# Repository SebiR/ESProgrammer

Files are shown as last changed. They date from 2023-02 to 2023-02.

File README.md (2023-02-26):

# ESProgrammer
A simple USB programming interface for ESP8266/ESP32

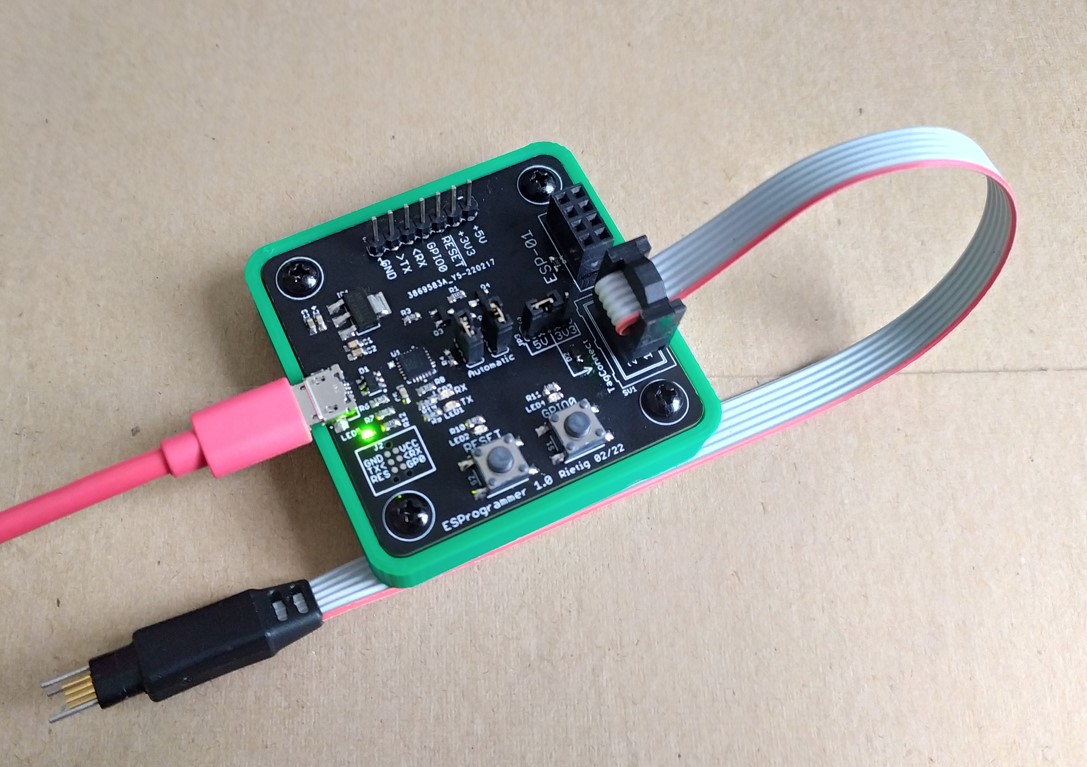
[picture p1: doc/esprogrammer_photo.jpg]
Programmer


## Features
* Automatic Reset/GPIO0
* TagConnect interface for custom devices
* Direct connector for ESP-01 modules

# Pinout and TagConnect
**RX of Programmer to RX of ESP and TX to TX**
(Which is a bit confusing to be honest)

The TagConnect connector follows my own standard which I've created for my devices using an ESP8266.

The device should utilize this pinout:
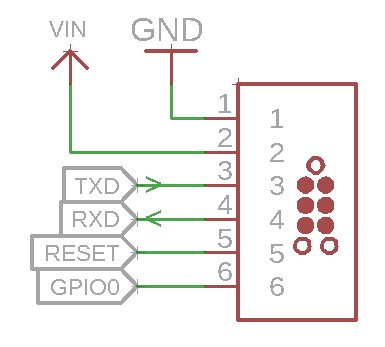
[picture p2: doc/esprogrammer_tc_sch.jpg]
Programmer


Whereas TXD goes to the TXD of the ESP8266 and RXD goes to the RXD of the ESP.

# Jumper
## Automatic
The two "Automatic" jumpers allow for an automatic trigger of the Reset and GPIO0 line during programming like on NodeMCU boards and Tasmotizer.
Manual resetting and triggering GPIO0 will always be possible with the push buttons.

## 3V3/5V
The other jumper near the TagConnect allows for a selection of the power supply voltage of the TagConnect. When my device has an LDO and 5V power supply, VCC will be set to 5V and the VCC pin on the device goes to the 5V input of the board.

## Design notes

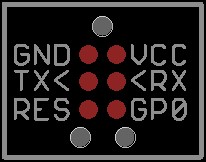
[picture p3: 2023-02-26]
doc/esprogrammer_tc.jpg

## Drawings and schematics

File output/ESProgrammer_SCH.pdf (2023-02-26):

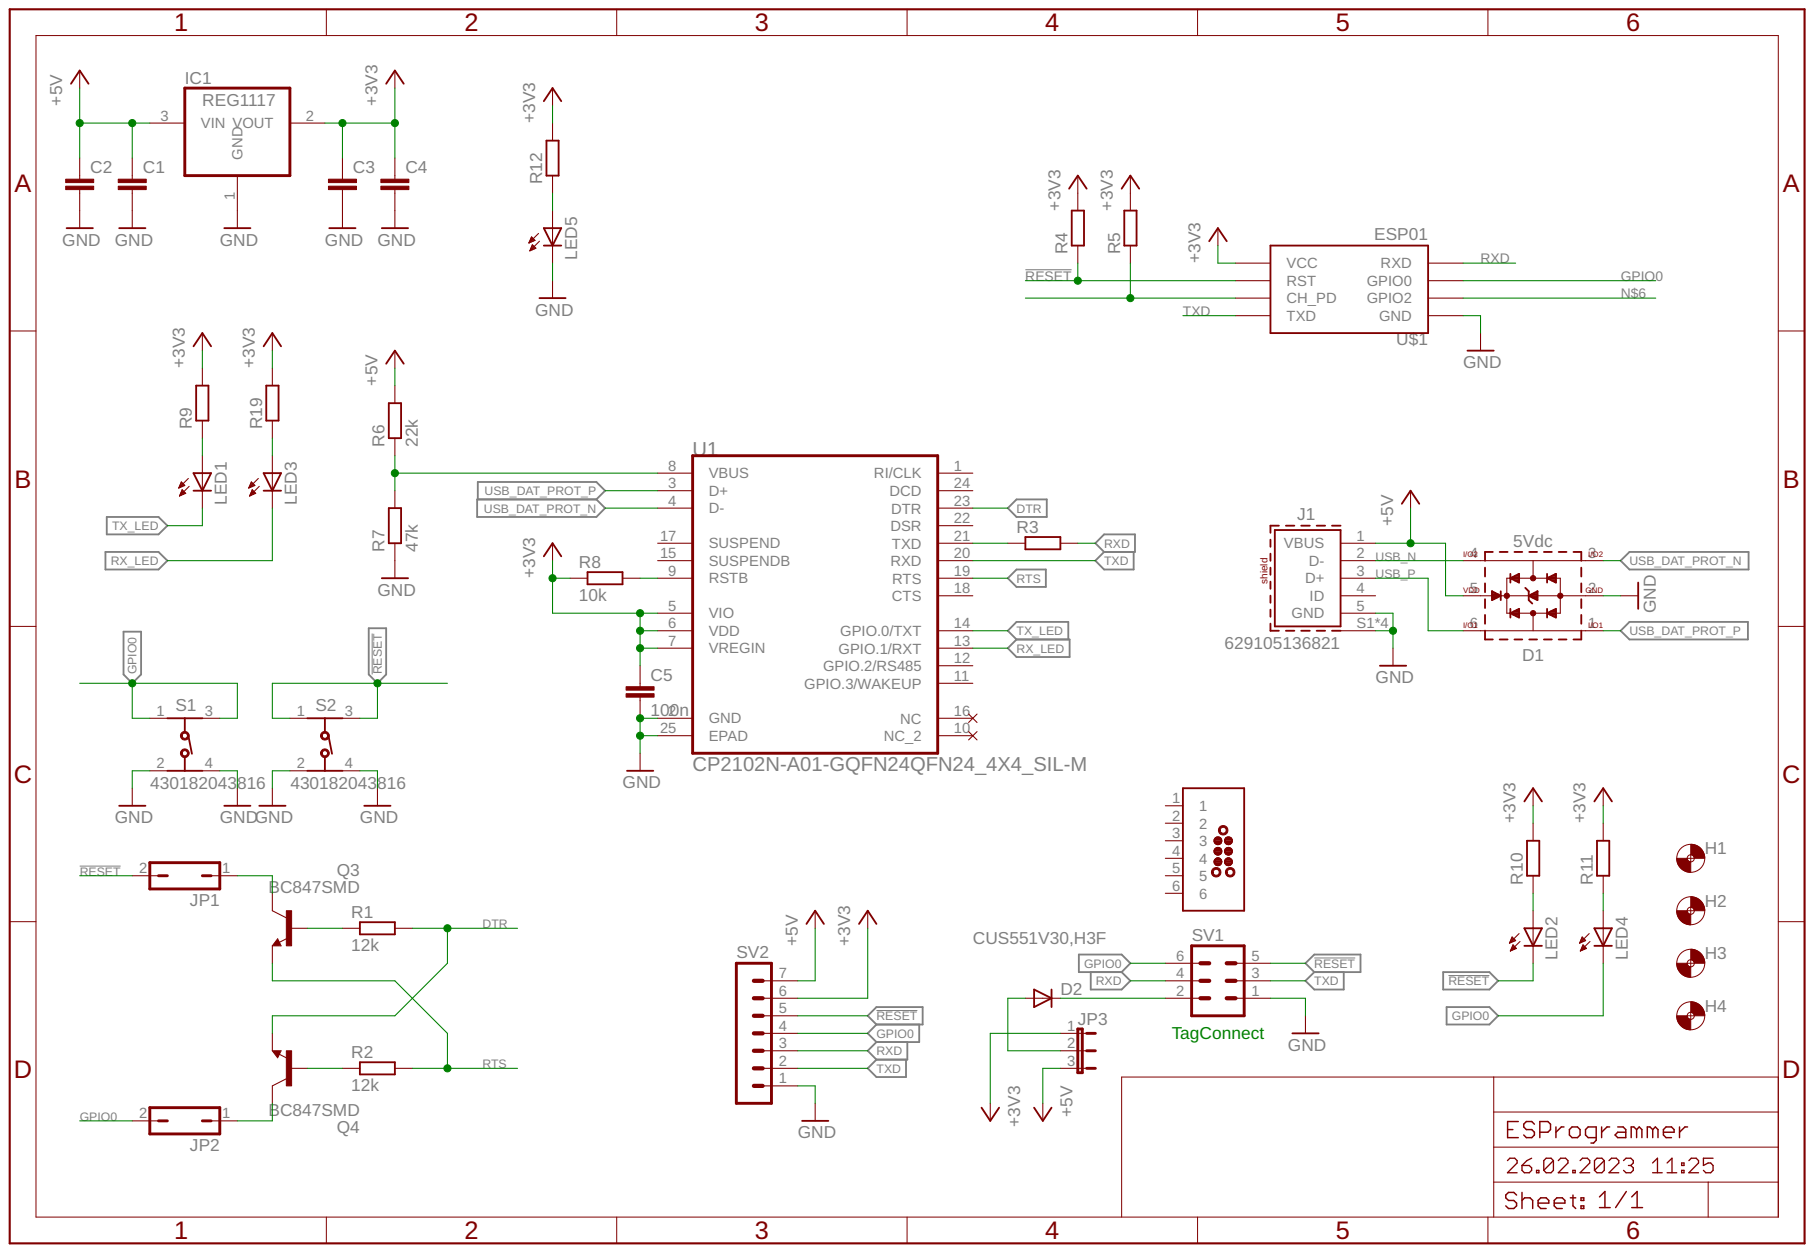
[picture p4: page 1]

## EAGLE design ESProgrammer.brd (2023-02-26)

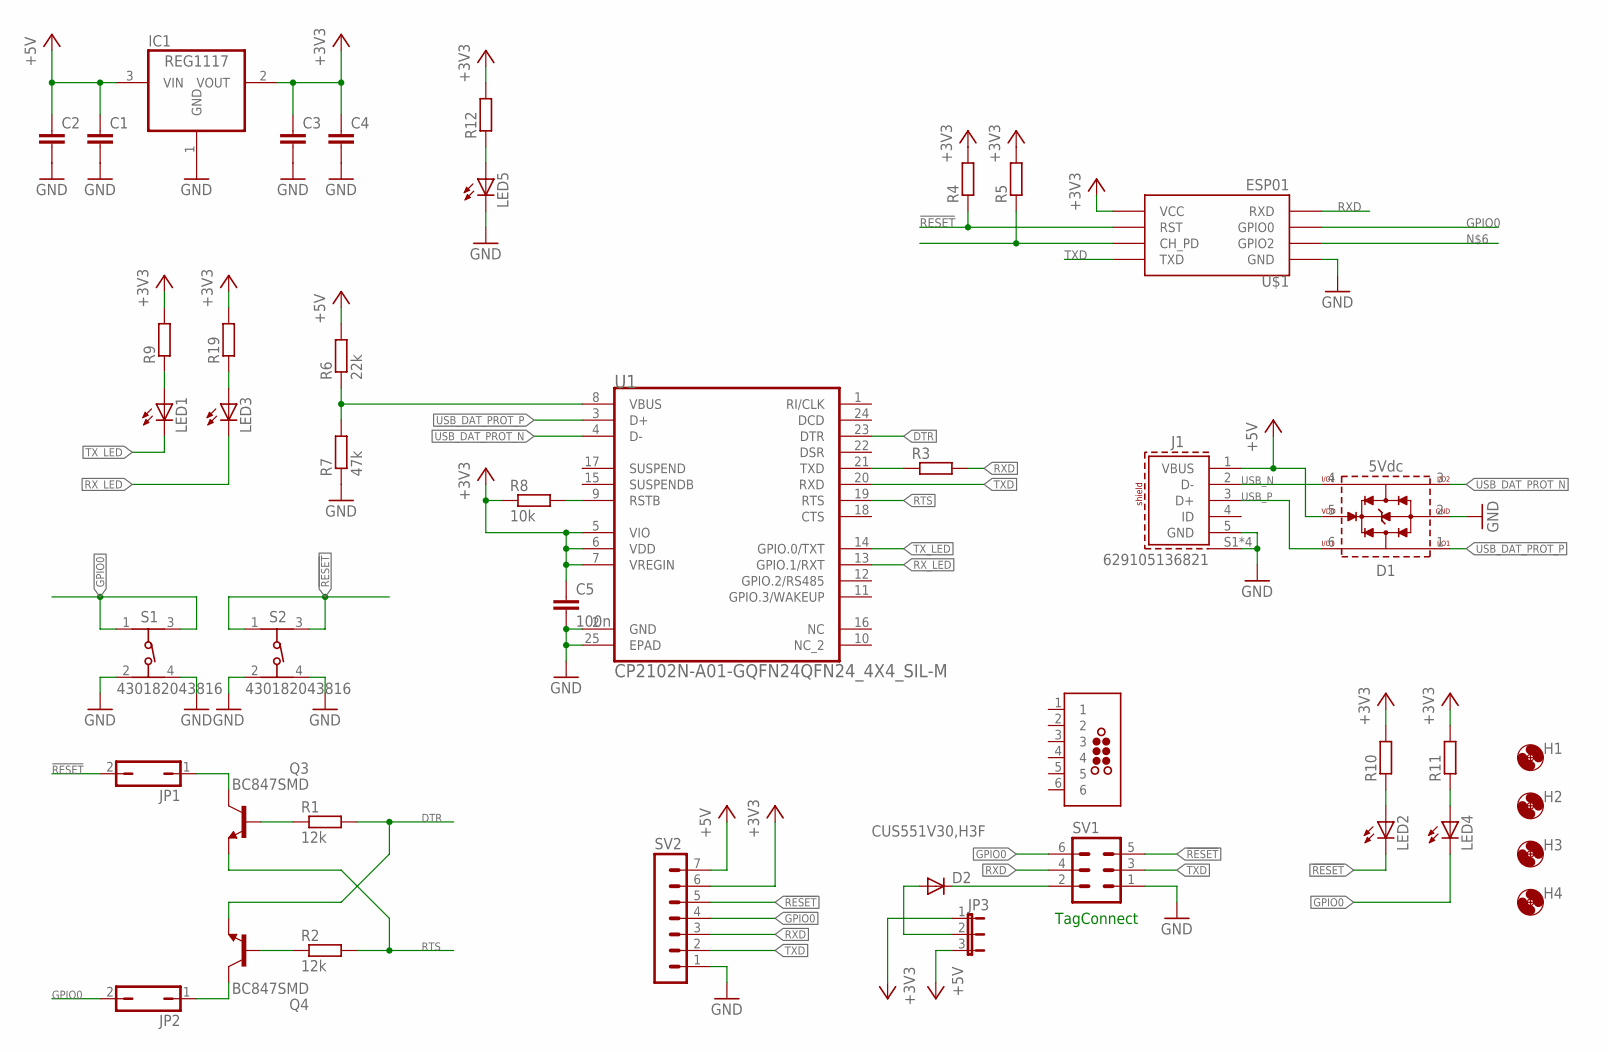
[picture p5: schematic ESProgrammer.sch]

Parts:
C1, C2, C3, C4: C-EUC0603; C0603
C5: 100n; C0603
D1: 5Vdc; WE-TVS_SOT23-6L
D2: CUS551V30,H3F; SOD323-R
H1, H2, H3, H4: MOUNT-HOLE3.2; 3,2
IC1: REG1117; SOT223
J1: 629105136821
J2: TC2030-MCP-NL
JP1, JP2: JP1Q; JP1
JP3: JP2E; JP2
LED1, LED2, LED3, LED4, LED5: LEDCHIP-LED0603; CHIP-LED0603
Q3, Q4: BC847SMD; SOT23
R1, R2: 12k; R0603
R3, R4, R5, R9, R10, R11, R12, R19: R-EU_R0603; R0603
R6: 22k; R0603
R7: 47k; R0603
R8: 10k; R0603
S1, S2: 430182043816
SV1: ML6
SV2: MA07-1
U1: CP2102N-A01-GQFN24QFN24_4X4_SIL-M; QFN24_4X4_SIL-M
U$1: ESP01

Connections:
2: J2.2
3: J2.3
!RESET: JP1.2, LED2.C, R4.1, S2.1, S2.3, SV1.5, SV2.5, U$1.RST
+3V3: C3.1, C4.1, C5.1, IC1.2 (VOUT), JP3.1, R4.2, R5.2, R8.1, R9.2, R10.2, R11.2, R12.2, R19.2, SV2.6, U1.5 (VIO), U1.6 (VDD), U1.7 (VREGIN), U$1.VCC
+5V: C1.1, C2.1, D1.5 (VDD), IC1.3 (VIN), J1.1 (VBUS), JP3.3, R6.2, SV2.7
DTR: Q4.2 (E), R1.2, U1.23 (DTR)
GND: C1.2, C2.2, C3.2, C4.2, C5.2, D1.2 (GND), IC1.1 (GND), J1.5 (GND), J1.S1 (SHIELD), J1.S2 (SHIELD), J1.S3 (SHIELD), J1.S4 (SHIELD), LED5.C, R7.1, S1.2, S1.4, S2.2, S2.4, SV1.1, SV2.1, U1.2 (GND), U1.25 (EPAD), U$1.GND
GPIO0: JP2.2, LED4.C, S1.1, S1.3, SV1.6, SV2.4, U$1.GPIO0
unnamed: Q3.1 (B), R1.1
unnamed: Q4.1 (B), R2.1
unnamed: JP1.1, Q3.3 (C)
unnamed: JP2.1, Q4.3 (C)
unnamed: R3.1, U1.21 (TXD)
unnamed: R5.1, U$1.CH_PD
unnamed: LED1.A, R9.1
unnamed: LED2.A, R10.1
unnamed: R6.1, R7.2, U1.8 (VBUS)
unnamed: R8.2, U1.9 (RSTB)
unnamed: LED4.A, R11.1
unnamed: LED5.A, R12.1
unnamed: D2.A, JP3.2
unnamed: D2.C, SV1.2
unnamed: LED3.A, R19.1
RTS: Q3.2 (E), R2.2, U1.19 (RTS)
RXD: R3.2, SV1.4, SV2.3, U$1.RX (RXD)
RX_LED: LED3.C, U1.13 (GPIO.1/RXT)
TXD: SV1.3, SV2.2, U1.20 (RXD), U$1.TX (TXD)
TX_LED: LED1.C, U1.14 (GPIO.0/TXT)
USB_DAT_PROT_N: D1.3 (I/O2), U1.4 (D-)
USB_DAT_PROT_P: D1.1 (I/O1), U1.3 (D+)
USB_N: D1.4 (I/O4), J1.2 (D-)
USB_P: D1.6 (I/O3), J1.3 (D+)

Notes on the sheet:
TagConnect

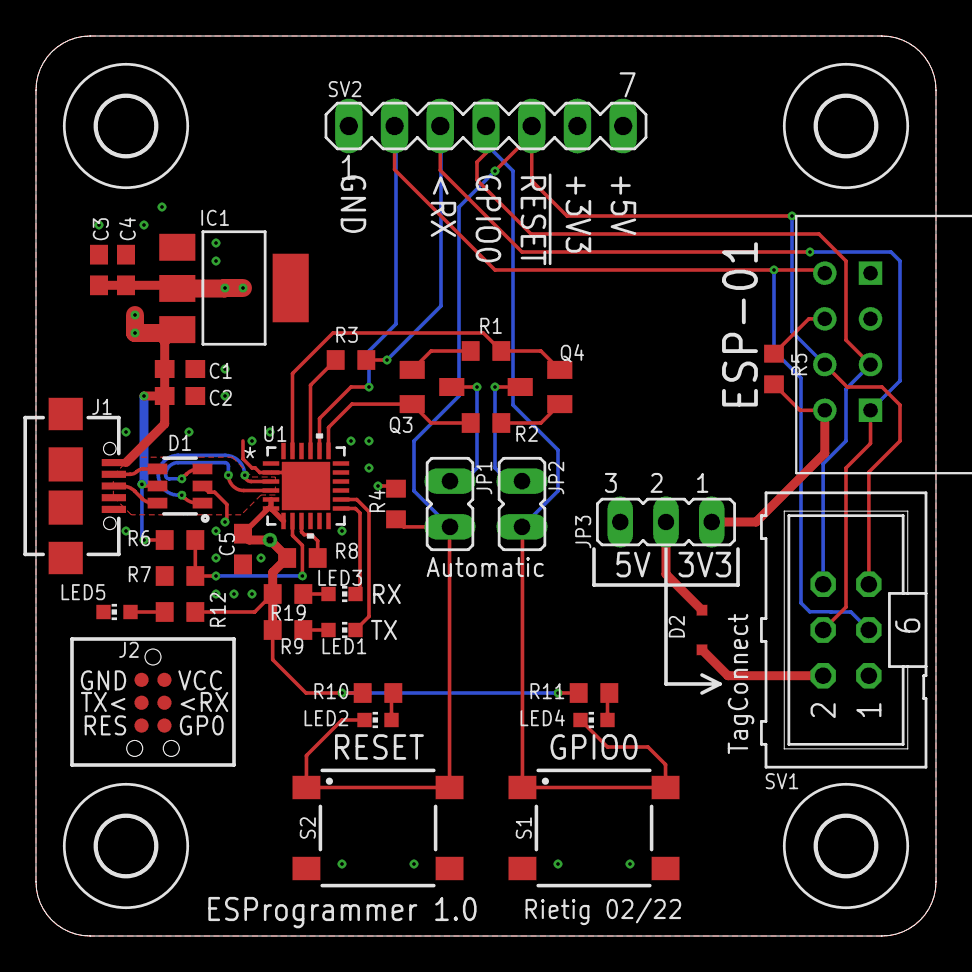
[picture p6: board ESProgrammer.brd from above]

Board: 4 copper layers, 50.0 x 50.0 mm, 43 parts (0 on the bottom side), 30 nets.

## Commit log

2023-02-25 added photo of the device
2023-02-26 * Updated documentation * Added GERBER and Schematic * Cleaned up the Schematics
    [ESProgrammer.brd, ESProgrammer.sch]
2023-02-26 * Updated Documentation * Cleaned up schematics * Added schematic PDF * Added Gerber files

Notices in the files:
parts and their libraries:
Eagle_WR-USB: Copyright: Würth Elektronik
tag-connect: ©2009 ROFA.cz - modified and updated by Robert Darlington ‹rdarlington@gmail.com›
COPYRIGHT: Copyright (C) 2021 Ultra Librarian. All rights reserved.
